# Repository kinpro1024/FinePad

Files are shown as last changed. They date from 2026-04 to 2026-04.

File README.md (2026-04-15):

# FinePad (kinpro1024 × ROY21)
### Precision Dual-Axis Macropad
FinePad is a macropad designed with fine pointer control for precision-requiring situations like colour curve modificatioins or timeline scrubbing.
FinePad comes with two independently scrolling Rotary Encoder Knobs for precision X and Y axis control of the Pointer.

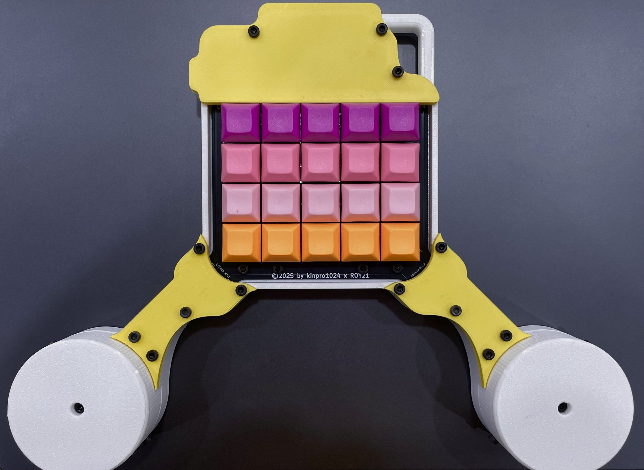
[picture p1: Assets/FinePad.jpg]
FinePad_No_Screen

This is the version of finepad with no screen. A version with mode toggle and screen is coming soon.

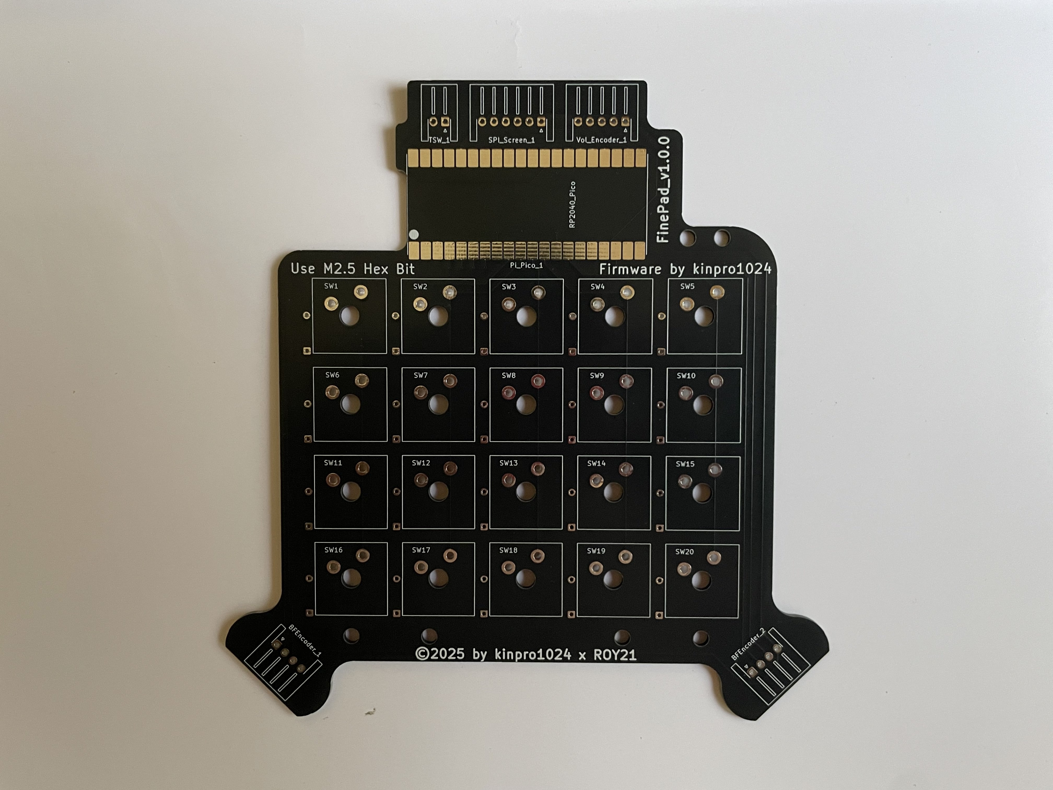
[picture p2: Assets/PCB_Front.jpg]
FinePad_PCB_Front

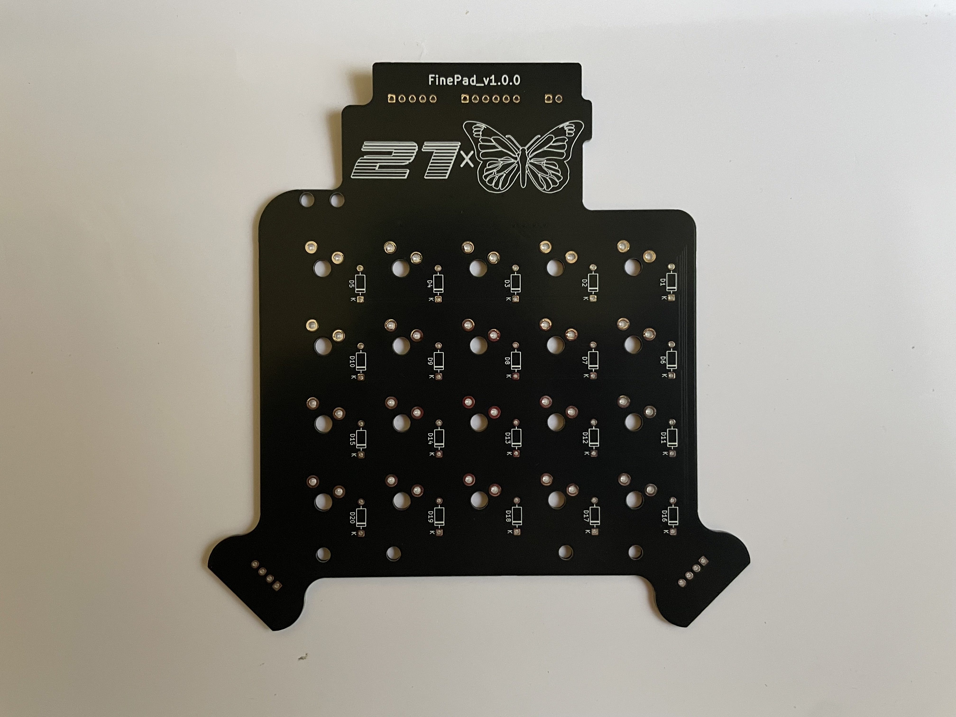
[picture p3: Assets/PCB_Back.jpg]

Finepad is built on a Custom PCB.

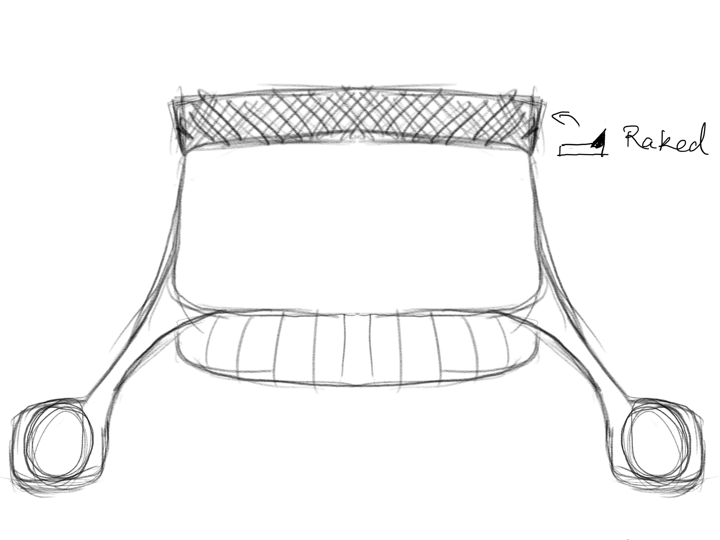
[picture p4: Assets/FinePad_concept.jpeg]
FinePad_Concept

*This is a concept sketch of the FinePad.*

## Why Fine pointer control
A macropad with dual fine scrolling knobs for X and Y control gives users a level of precision that mice and trackpads struggle to achieve. When working with:
- Colour Curves
- Exposure
- Fine Parameter Sliders
As even small unintended movements with a mouse can lead to inconsistent results in these situations.

**Dedicated knobs allow for smooth, incremental control, making subtle adjustments far more intuitive and repeatable.** Separating X and Y into physical controls also reduces cognitive load, since each axis becomes a deliberate action rather than a coordinated hand movement. This is especially valuable in workflows like:
- Photo Editing
- Colour Grading
- Audio Tuning
Where precision directly impacts output quality. Overall, it transforms delicate adjustments from a frustrating task into a controlled, tactile experience.

## Hardware Overview
FinePad uses a custom PCB as it's base:
- Raspberry Pi Pico handles Firmware.
- Two AS5600 Hall Effect Absolute Encoders.

# FinePad (screenless) was completed on 10/Apr/2026. It is a collaboration between kinpro1024 and ROY21.
# FinePad will get a toggle switch, screen and volume knob in an upcoming update. The full firmware will also come soon.

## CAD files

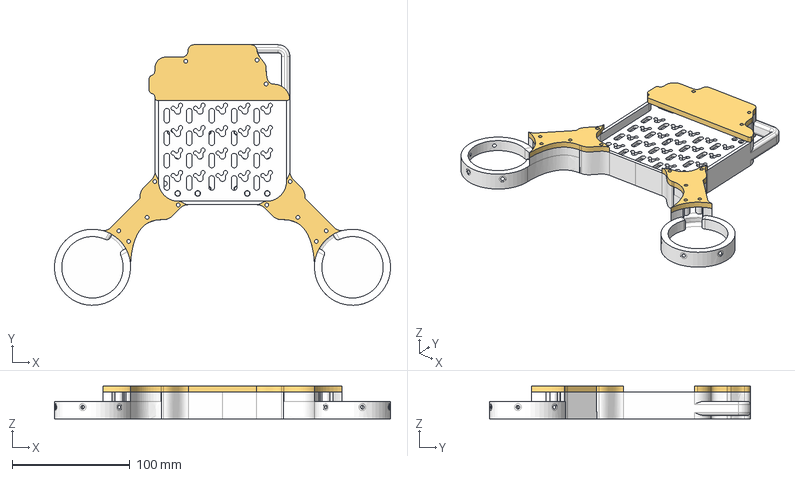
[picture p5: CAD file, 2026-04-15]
Mechanical/STEPs/FinePad_Enclosure.step
285.5 x 221.4 x 28.0 mm
Enclosure
Encoder_Arms
Encoder_Arm_Covers
Mounting_Plate

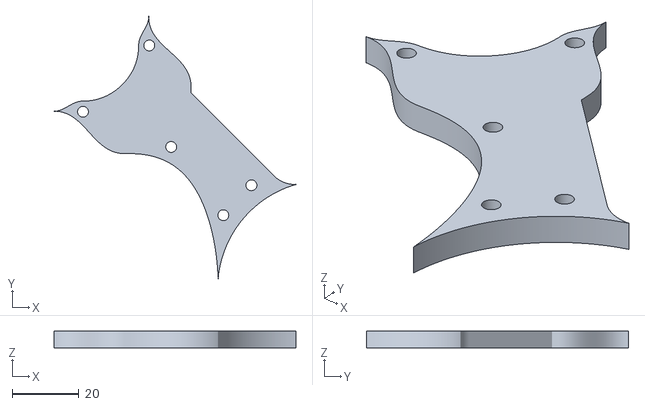
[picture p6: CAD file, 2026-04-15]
Mechanical/STLs/Encoder_Arm_Cover_R.stl
72.5 x 78.5 x 5.00

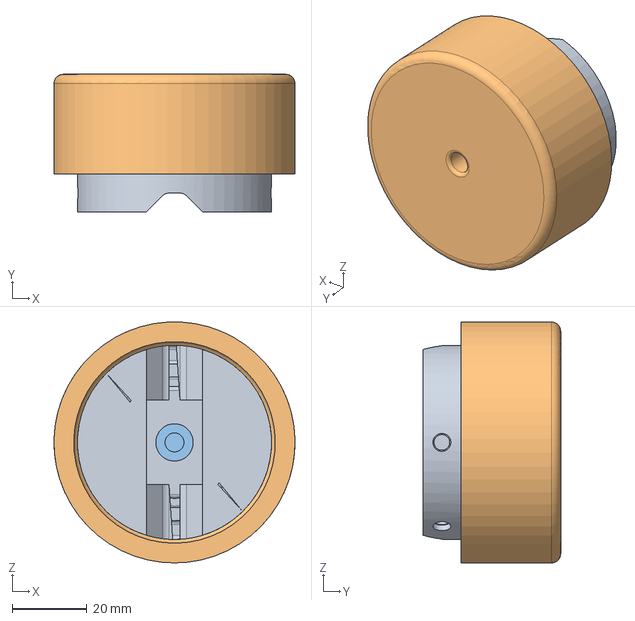
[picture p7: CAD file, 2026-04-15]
Mechanical/STEPs/Knob.step
64.6 x 36.9 x 64.5 mm

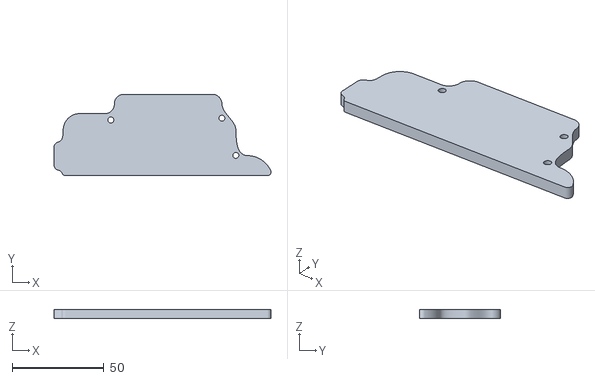
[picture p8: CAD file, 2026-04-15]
Mechanical/STLs/Mounting_Plate_No_Screen.stl
118.5 x 44.5 x 5.00

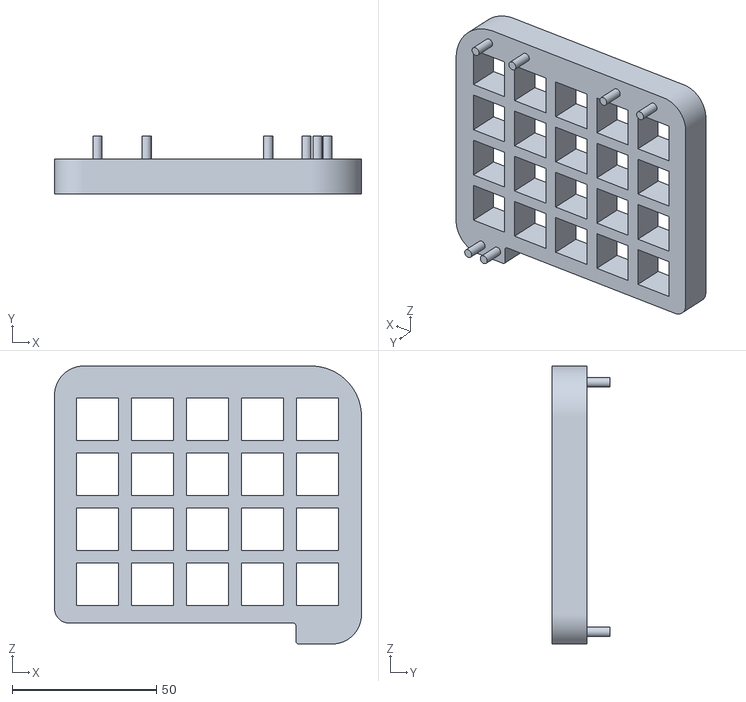
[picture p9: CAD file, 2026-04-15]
Mechanical/STLs/Alignment_Grid.stl
106.3 x 20.0 x 96.2

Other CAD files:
Mechanical/STLs/Encoder_Arm_Cover_L.stl

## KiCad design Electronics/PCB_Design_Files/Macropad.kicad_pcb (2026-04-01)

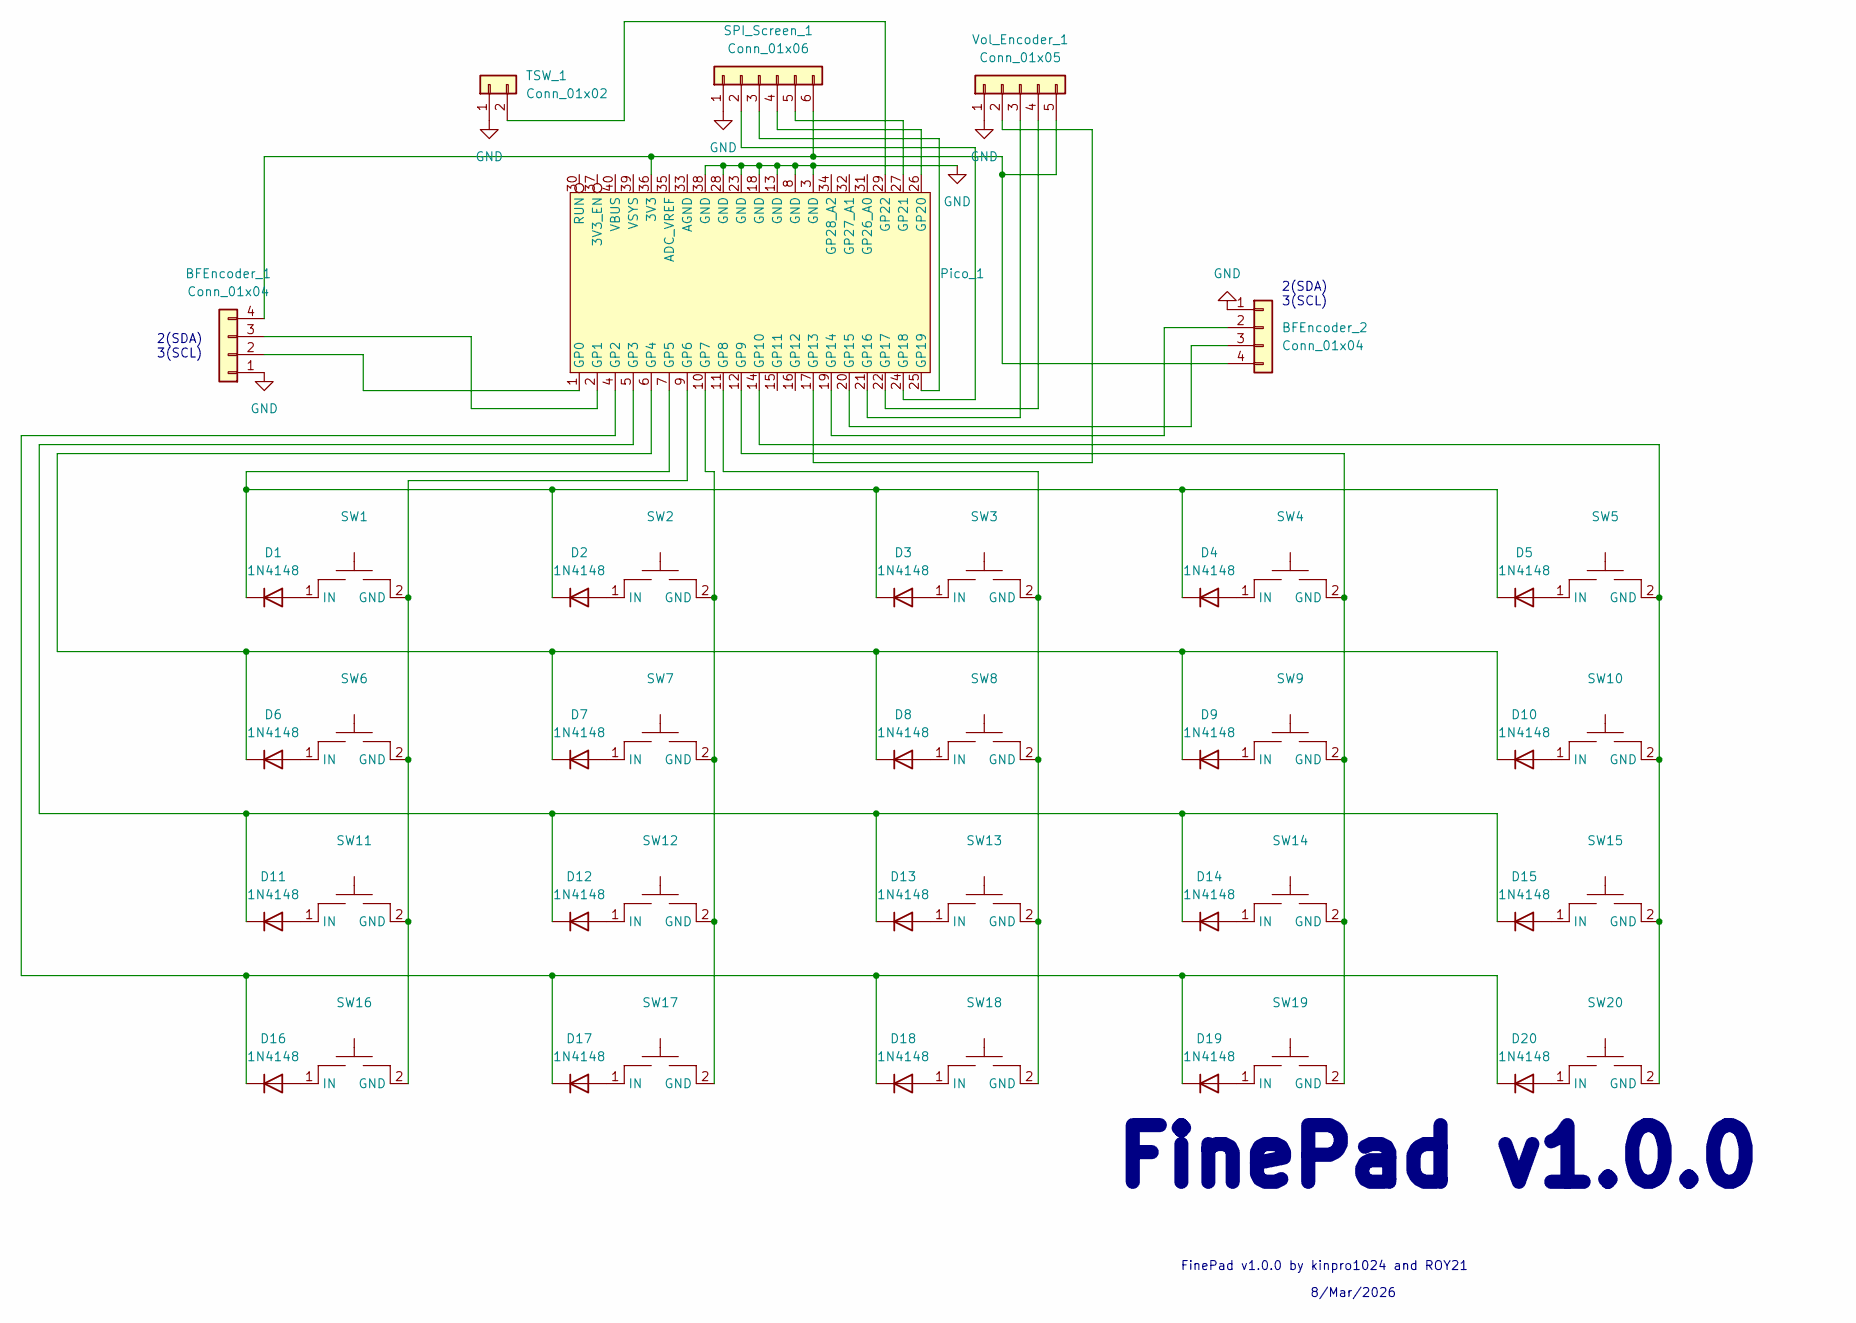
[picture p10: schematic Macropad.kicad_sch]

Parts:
BFEncoder_1, BFEncoder_2: Conn_01x04; JST_XH_S4B-XH-A-1_1x04_P2.50mm_Horizontal
D1, D2, D3, D4, D5, D6, D7, D8, D9, D10, D11, D12, D13, D14, D15, D16, D17, D18, D19, D20: 1N4148; D_DO-35_SOD27_P7.62mm_Horizontal
Pico_1: Pico_SMT
SPI_Screen_1: Conn_01x06; JST_XH_S6B-XH-A-1_1x06_P2.50mm_Horizontal
SW1, SW2, SW3, SW4, SW5, SW6, SW7, SW8, SW9, SW10, SW11, SW12, SW13, SW14, SW15, SW16, SW17, SW18, SW19, SW20: Gateron_G_Pro_3
TSW_1: Conn_01x02; JST_XH_S2B-XH-A-1_1x02_P2.50mm_Horizontal
Vol_Encoder_1: Conn_01x05; JST_XH_S5B-XH-A-1_1x05_P2.50mm_Horizontal

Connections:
GND: BFEncoder_1.1, BFEncoder_2.1, Pico_1.3 (GND), Pico_1.8 (GND), Pico_1.13 (GND), Pico_1.18 (GND), Pico_1.23 (GND), Pico_1.28 (GND), Pico_1.38 (GND), SPI_Screen_1.1, TSW_1.1, Vol_Encoder_1.1; also elsewhere on the board
unnamed 1: BFEncoder_1.2, Pico_1.1 (GP0); also elsewhere on the board
unnamed 2: BFEncoder_1.3, Pico_1.2 (GP1); also elsewhere on the board
unnamed 3: BFEncoder_1.4, BFEncoder_2.4, Pico_1.36 (3V3), SPI_Screen_1.6, Vol_Encoder_1.5; also elsewhere on the board
unnamed 4: BFEncoder_2.2, Pico_1.19 (GP14); also elsewhere on the board
unnamed 5: BFEncoder_2.3, Pico_1.20 (GP15); also elsewhere on the board
unnamed: D1.2 (A), SW1.1 (IN)
unnamed 7: D1.1 (K), D2.1 (K), D3.1 (K), D4.1 (K), D5.1 (K), Pico_1.7 (GP5); also elsewhere on the board
unnamed: D2.2 (A), SW2.1 (IN)
unnamed: D3.2 (A), SW3.1 (IN)
unnamed: D4.2 (A), SW4.1 (IN)
unnamed: D5.2 (A), SW5.1 (IN)
unnamed: D6.2 (A), SW6.1 (IN)
unnamed: D7.2 (A), SW7.1 (IN)
unnamed: D8.2 (A), SW8.1 (IN)
unnamed: D9.2 (A), SW9.1 (IN)
unnamed: D10.2 (A), SW10.1 (IN)
unnamed 17: D6.1 (K), D7.1 (K), D8.1 (K), D9.1 (K), D10.1 (K), Pico_1.6 (GP4); also elsewhere on the board
unnamed: D11.2 (A), SW11.1 (IN)
unnamed 19: D11.1 (K), D12.1 (K), D13.1 (K), D14.1 (K), D15.1 (K), Pico_1.5 (GP3); also elsewhere on the board
unnamed: D12.2 (A), SW12.1 (IN)
unnamed: D13.2 (A), SW13.1 (IN)
unnamed: D14.2 (A), SW14.1 (IN)
unnamed: D15.2 (A), SW15.1 (IN)
unnamed: D16.2 (A), SW16.1 (IN)
unnamed 25: D16.1 (K), D17.1 (K), D18.1 (K), D19.1 (K), D20.1 (K), Pico_1.4 (GP2); also elsewhere on the board
unnamed: D17.2 (A), SW17.1 (IN)
unnamed: D18.2 (A), SW18.1 (IN)
unnamed: D19.2 (A), SW19.1 (IN)
unnamed: D20.2 (A), SW20.1 (IN)
unnamed 30: Pico_1.9 (GP6), SW1.2 (GND), SW6.2 (GND), SW11.2 (GND), SW16.2 (GND); also elsewhere on the board
unnamed 31: Pico_1.10 (GP7), SW2.2 (GND), SW7.2 (GND), SW12.2 (GND), SW17.2 (GND); also elsewhere on the board
unnamed 32: Pico_1.11 (GP8), SW3.2 (GND), SW8.2 (GND), SW13.2 (GND), SW18.2 (GND); also elsewhere on the board
unnamed 33: Pico_1.12 (GP9), SW4.2 (GND), SW9.2 (GND), SW14.2 (GND), SW19.2 (GND); also elsewhere on the board
unnamed 34: Pico_1.14 (GP10), SW5.2 (GND), SW10.2 (GND), SW15.2 (GND), SW20.2 (GND); also elsewhere on the board
unnamed 35: Pico_1.17 (GP13), Vol_Encoder_1.2; also elsewhere on the board
unnamed 36: Pico_1.21 (GP16), Vol_Encoder_1.3; also elsewhere on the board
unnamed 37: Pico_1.22 (GP17), Vol_Encoder_1.4; also elsewhere on the board
unnamed 38: Pico_1.24 (GP18), SPI_Screen_1.2; also elsewhere on the board
unnamed 39: Pico_1.25 (GP19), SPI_Screen_1.3; also elsewhere on the board
unnamed 40: Pico_1.26 (GP20), SPI_Screen_1.4; also elsewhere on the board
unnamed 41: Pico_1.27 (GP21), SPI_Screen_1.5; also elsewhere on the board
unnamed 42: Pico_1.29 (GP22), TSW_1.2; also elsewhere on the board

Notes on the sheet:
FinePad v1.0.0 by kinpro1024 and ROY21
8/Mar/2026
2(SDA) 3(SCL)
FinePad v1.0.0

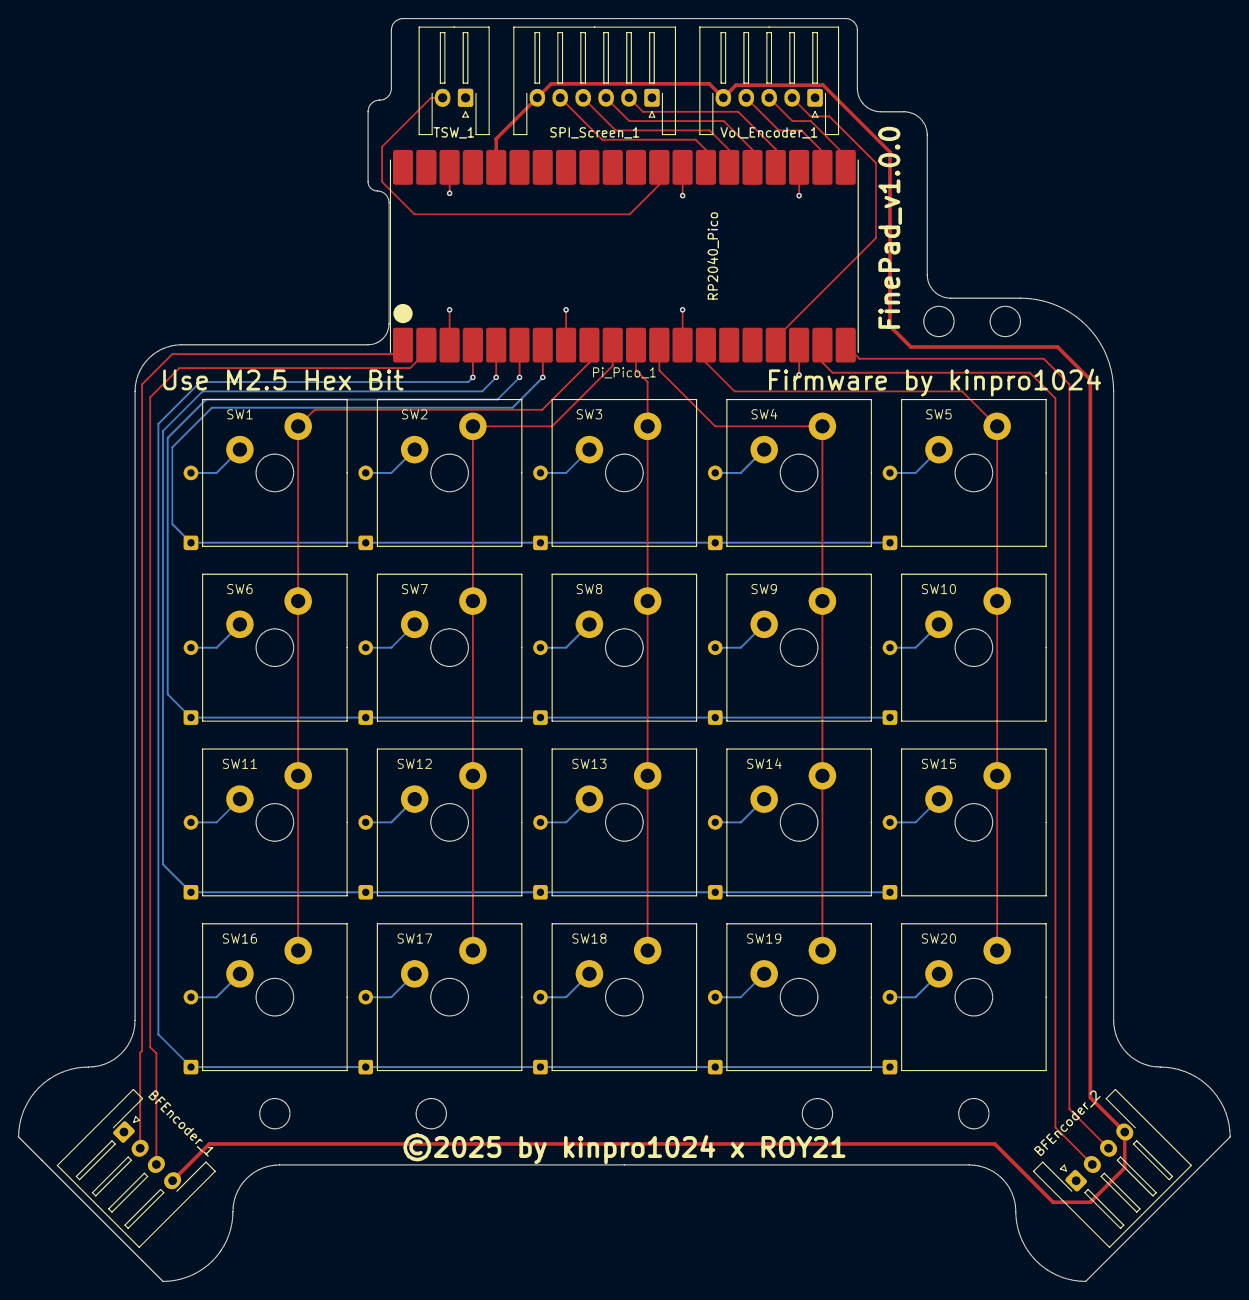
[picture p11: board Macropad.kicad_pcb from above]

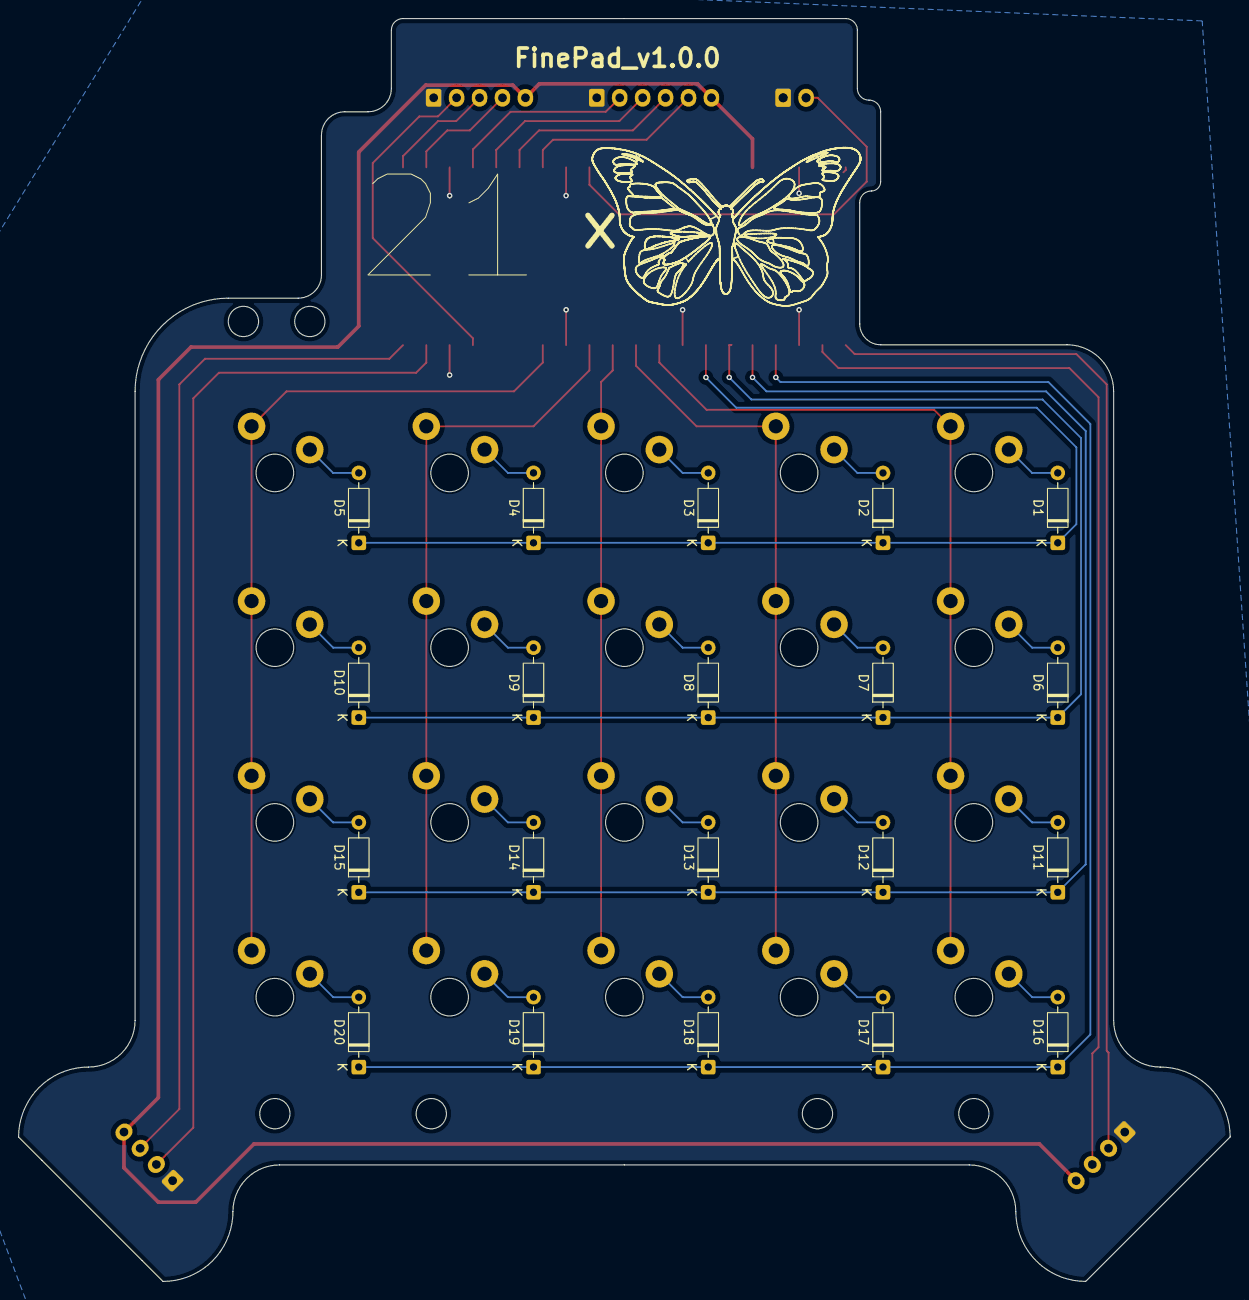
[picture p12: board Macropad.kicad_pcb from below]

Board: 2 copper layers, 132.1 x 137.7 mm, 46 parts (20 on the bottom side), 43 nets.

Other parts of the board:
Pi_Pico_1: RP2040_Pico; Pico_SMT

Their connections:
GND: Pi_Pico_1.3 (GND), Pi_Pico_1.8 (GND), Pi_Pico_1.13 (GND), Pi_Pico_1.18 (GND), Pi_Pico_1.23 (GND), Pi_Pico_1.28 (GND), Pi_Pico_1.38 (GND); also elsewhere on the board
unnamed 1: Pi_Pico_1.1 (GP0); also elsewhere on the board
unnamed 2: Pi_Pico_1.2 (GP1); also elsewhere on the board
unnamed 3: Pi_Pico_1.36 (3V3); also elsewhere on the board
unnamed 4: Pi_Pico_1.19 (GP14); also elsewhere on the board
unnamed 5: Pi_Pico_1.20 (GP15); also elsewhere on the board
unnamed 7: Pi_Pico_1.7 (GP5); also elsewhere on the board
unnamed 17: Pi_Pico_1.6 (GP4); also elsewhere on the board
unnamed 19: Pi_Pico_1.5 (GP3); also elsewhere on the board
unnamed 25: Pi_Pico_1.4 (GP2); also elsewhere on the board
unnamed 30: Pi_Pico_1.9 (GP6); also elsewhere on the board
unnamed 31: Pi_Pico_1.10 (GP7); also elsewhere on the board
unnamed 32: Pi_Pico_1.11 (GP8); also elsewhere on the board
unnamed 33: Pi_Pico_1.12 (GP9); also elsewhere on the board
unnamed 34: Pi_Pico_1.14 (GP10); also elsewhere on the board
unnamed 35: Pi_Pico_1.17 (GP13); also elsewhere on the board
unnamed 36: Pi_Pico_1.21 (GP16); also elsewhere on the board
unnamed 37: Pi_Pico_1.22 (GP17); also elsewhere on the board
unnamed 38: Pi_Pico_1.24 (GP18); also elsewhere on the board
unnamed 39: Pi_Pico_1.25 (GP19); also elsewhere on the board
unnamed 40: Pi_Pico_1.26 (GP20); also elsewhere on the board
unnamed 41: Pi_Pico_1.27 (GP21); also elsewhere on the board
unnamed 42: Pi_Pico_1.29 (GP22); also elsewhere on the board

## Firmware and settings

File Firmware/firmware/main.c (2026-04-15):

#include "pico/stdlib.h"
#include "matrix/matrix.h"
#include "event/event.h"
#include "hid/hid.h"
#include "keymap/keymap.h"
#include "macro/macro.h"
#include "tusb.h"

int main() {

    stdio_init_all();
    matrix_init();
    event_init();
    hid_init();

    // movement state
    bool move_up = false;
    bool move_down = false;
    bool move_left = false;
    bool move_right = false;

    while (true) {

        matrix_scan();
        tud_task();
        macro_task();

        key_event_t e;

        while (event_get(&e)) {

            key_action_t action = keymap_get_action(e.row, e.col);

            // block ALL input during macro
            if (macro_is_running()) continue;

            // ================= PRESS =================
            if (e.type == EVENT_KEY_PRESS) {

                switch (action.type) {

                    case KEY_TYPE_MACRO:
                        macro_start(action.macro);
                        break;

                    case KEY_TYPE_NORMAL:
                        hid_send_key(action.keycode, true);
                        break;

                    case KEY_TYPE_MOUSE_MOVE:

                        if (action.dx == 0 && action.dy == -5) move_up = true;
                        if (action.dx == 0 && action.dy ==  5) move_down = true;
                        if (action.dx == -5 && action.dy == 0) move_left = true;
                        if (action.dx ==  5 && action.dy == 0) move_right = true;

                        break;

                    case KEY_TYPE_MOUSE_BUTTON:
                        hid_mouse_buttons(action.mouse_button);
                        break;

                    case KEY_TYPE_MOUSE_TOGGLE:
                        hid_mouse_toggle_left();   // ✅ NEW
                        break;
                }
            }

            // ================= RELEASE =================
            if (e.type == EVENT_KEY_RELEASE) {

                switch (action.type) {

                    case KEY_TYPE_NORMAL:
                        hid_send_key(action.keycode, false);
                        break;

                    case KEY_TYPE_MOUSE_MOVE:

                        if (action.dx == 0 && action.dy == -5) move_up = false;
                        if (action.dx == 0 && action.dy ==  5) move_down = false;
                        if (action.dx == -5 && action.dy == 0) move_left = false;
                        if (action.dx ==  5 && action.dy == 0) move_right = false;

                        break;

                    case KEY_TYPE_MOUSE_BUTTON:
                        hid_mouse_buttons(0); // release
                        break;

                    case KEY_TYPE_MOUSE_TOGGLE:
                        // ❌ DO NOTHING (important)
                        break;
                }
            }
        }

        // ================= CONTINUOUS MOUSE MOVE =================
        int8_t dx = 0;
        int8_t dy = 0;

        if (move_up)    dy -= 3;
        if (move_down)  dy += 3;
        if (move_left)  dx -= 3;
        if (move_right) dx += 3;

        if (dx != 0 || dy != 0) {
            hid_mouse_move(dx, dy);
        }

        sleep_ms(1);
    }
}

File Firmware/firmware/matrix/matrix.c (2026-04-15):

#include "matrix/matrix.h"
#include "config/config.h"
#include "pico/stdlib.h"

static bool matrix_state[MATRIX_ROWS][MATRIX_COLS];

void matrix_init(void) {

    //set rows to drive
    for (uint8_t r = 0; r < MATRIX_ROWS; r++) {
        gpio_init(row_pins[r]);
        gpio_set_dir(row_pins[r], GPIO_OUT);
        gpio_put(row_pins[r], 1); //Idle High
    }

    for (uint8_t c = 0; c < MATRIX_COLS; c++) {
        gpio_init(col_pins[c]);
        gpio_set_dir(col_pins[c], GPIO_IN);
        gpio_pull_up(col_pins[c]);
    }
}

void matrix_scan() {

    for(uint8_t r = 0; r < MATRIX_ROWS; r++) {
        gpio_put(row_pins[r], 0); //Drive row low
        sleep_us(5);

        for(uint8_t c = 0; c < MATRIX_COLS; c++) {
            bool is_pressed = !gpio_get(col_pins[c]);
            matrix_state[r][c] = is_pressed;
        }
        gpio_put(row_pins[r], 1);
    }
}

bool get_matrix_state(uint8_t row, uint8_t col) {
    return matrix_state[row][col];
}

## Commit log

2026-04-01 added Electroics files
    [Macropad-B_Cu.gbr, Macropad-B_Mask.gbr, Macropad-B_Paste.gbr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]
2026-04-15 Added Mechanical Files
    [Alignment_Grid.stl, Encoder_Arm_Cover_L.stl, Encoder_Arm_Cover_R.stl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]
2026-04-15 Added Current Firmware Files

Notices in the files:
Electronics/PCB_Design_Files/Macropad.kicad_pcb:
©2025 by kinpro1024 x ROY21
